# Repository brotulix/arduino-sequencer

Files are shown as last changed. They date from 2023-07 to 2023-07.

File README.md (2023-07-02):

# arduino-sequencer
A simple Arduino-based sequencer to turn masthead preamplifier and power amplifier on and off in sequence when beginning and ending transmission, as well as inhibiting transmit on a Yaesu radio (FT-991 or FT-817).

Additions will be switching coax relays to allow co-listening with an SDR during receive period.

## PTT

The same sequencer is intended for 144 and 432 MHz operation, for which I own power amplifiers with opposite PTT controls; one will activate when PTT is pulled high, one will activate when PTT is pulled low. To solve this with the least hassle, I'll control the PTT using a photo diode surrounded by four diodes, and select active high or active low using a toggle switch:

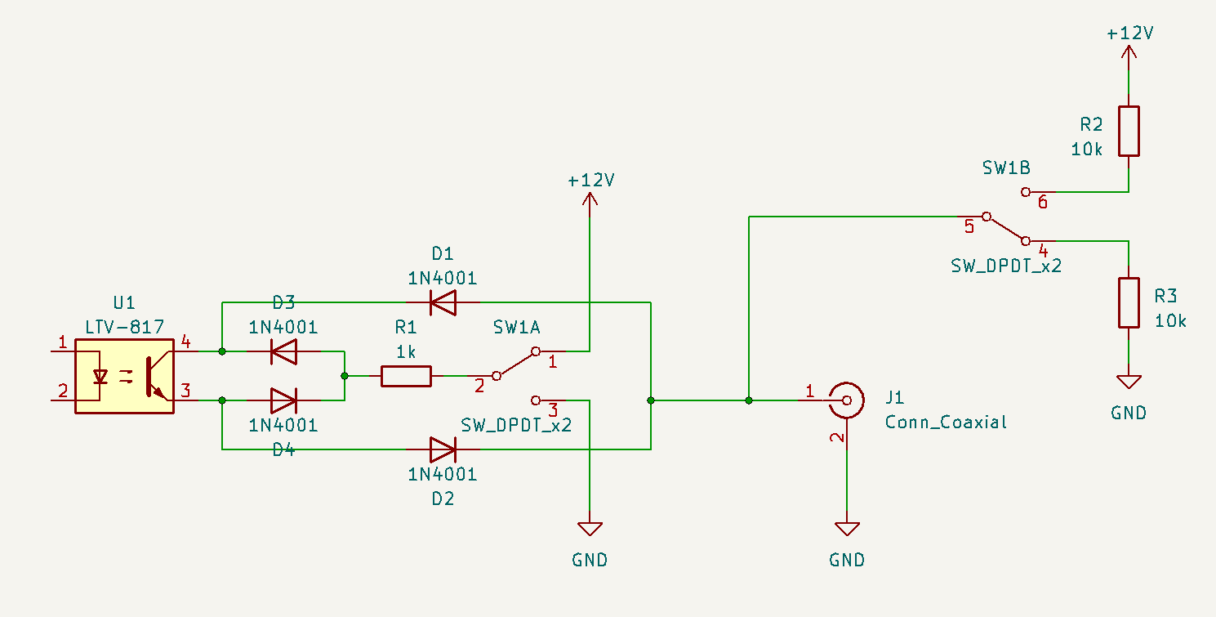
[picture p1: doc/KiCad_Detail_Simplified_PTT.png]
Simplified PA PTT circuit


Here, J1 (an RCA socket) connects to the PTT input of either KLM electronics VHF PA or Microwave Modules MML 432/100 UHF PA. SW1 is DPDT and will flip voltages for both the opto-coupler and the pull up/down.

# State machine
So, a state machine may be a useful method to keep track of where one is in the sequence of events going from RX -> TX or TX -> RX.

Maybe some form of table-based state machine to easily add stages and transitioning to the right next state?

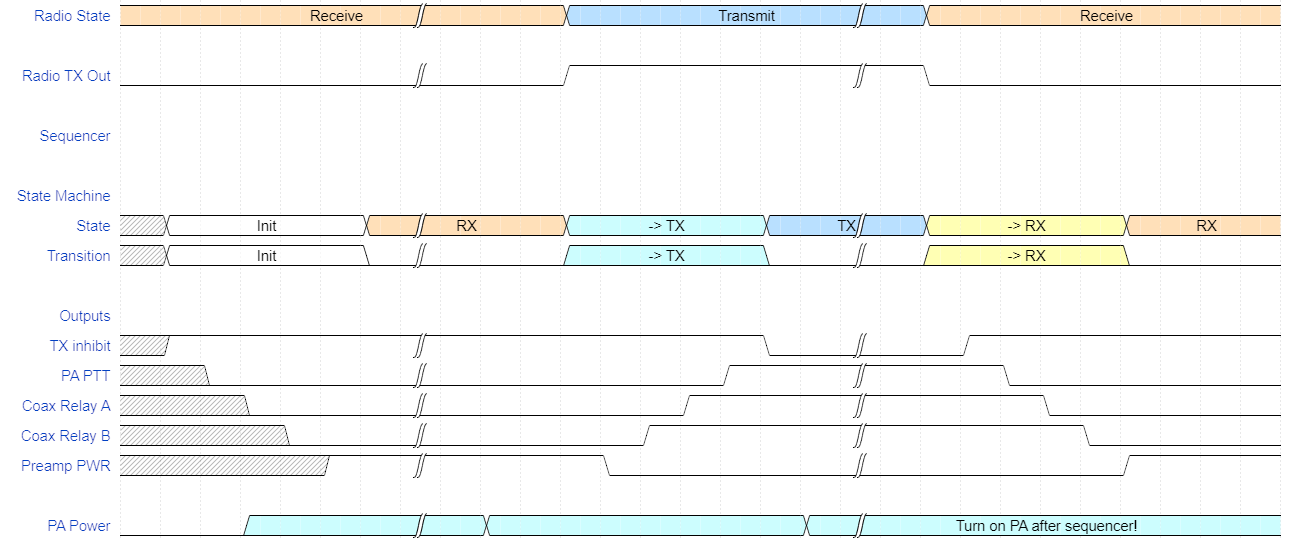
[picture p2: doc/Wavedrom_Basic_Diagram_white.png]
Basic state machine timing diagram


Whether I'll use an interrupt to trigger on flank or simply evaluate high/low state in a loop is TBD.

## Initialization / Power-up
The system starts up in an unknown state as of yet. I think it should sets some signals to a safe-ish state immediately, then progresses through some sequence of events to reach a true RX state.

Probably the most important detail is that the PA should be switched on after the sequencer.

> Should the radio be switched on after the sequencer, too, to make sure TX inhibit is on from the start?

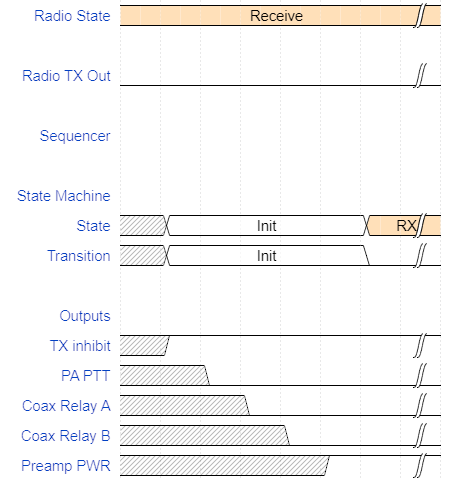
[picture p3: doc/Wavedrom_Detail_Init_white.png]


## RX -> TX
The sequence when going from RX to TX is something like this:

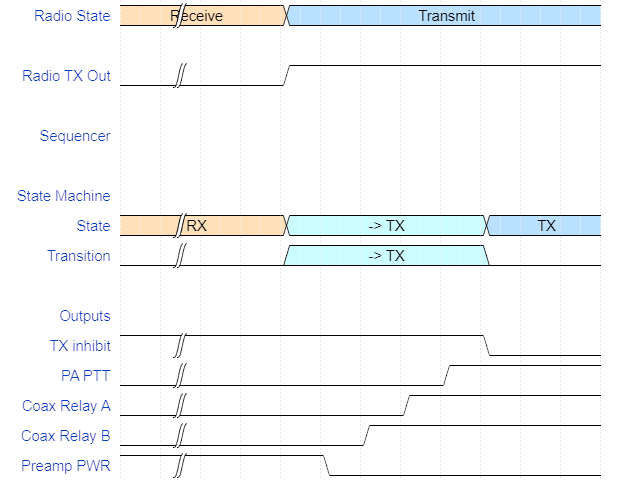
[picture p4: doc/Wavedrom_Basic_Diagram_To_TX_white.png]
Generic timing diagram for state transition from TX to RX


### RX -> TX -> RX
The special case when TX goes low before during the transition from RX to TX should go something like this:

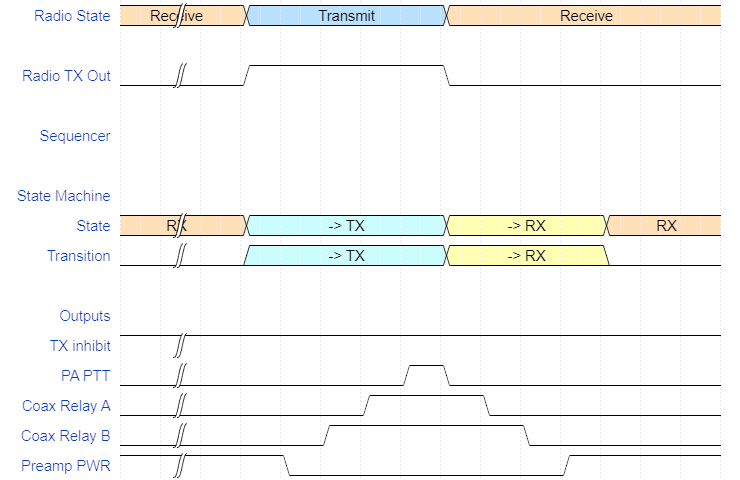
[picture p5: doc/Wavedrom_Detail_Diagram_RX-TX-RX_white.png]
Generic timing diagram for state transition from RX, partly to TX, then back to RX


See *dwell time*.

## TX -> RX
Transitioning from TX back to RX:

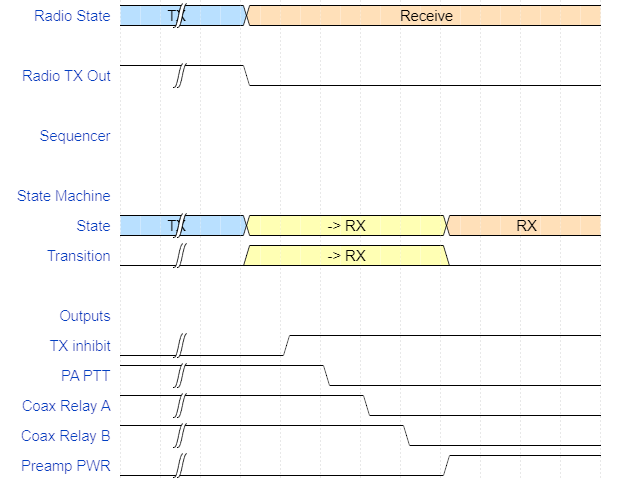
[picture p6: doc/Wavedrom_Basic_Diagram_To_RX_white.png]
Timing diagram for state transition from TX to RX


### TX -> RX -> TX
The special case where one is transmitting, but then experience a glitch in TX from radio which begins a transition to RX, but then returns to TX during the transition phase.

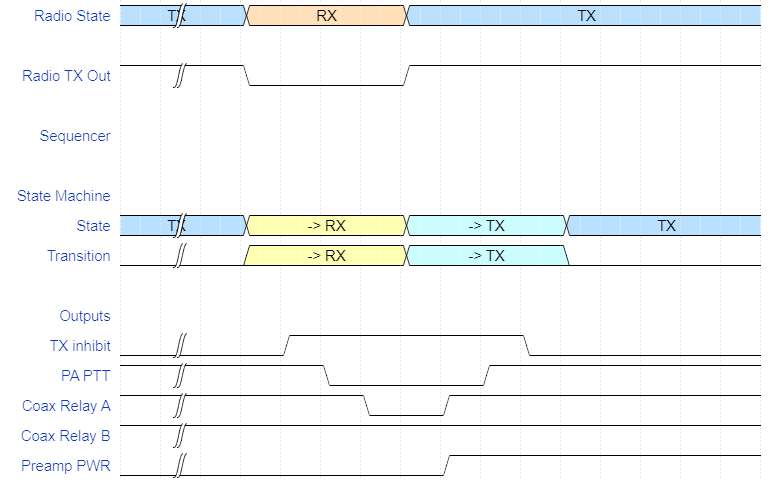
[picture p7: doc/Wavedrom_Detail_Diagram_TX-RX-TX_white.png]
Timing diagram for state transition from RX, partly to TX, then back to RX


See *dwell time*.

# Dwell time
> Add a potensiometer/encoder to set the delay for each stage? First design may use the same delay for both entering and leaving transmit state, but perhaps allow for faster delays going one direction or the other later?

Upon entering every state, set a minimum dwell time for that state to allow for energy to stabilize in the system (eg. DC bias for preamp; depending on coax length, you may want a certain minimum delay to allow the rising edge to reach full round-trip).

This may remove the need for a "inter-state" delay period, and depending on what the Radio TX signal is when entering (or exiting) the state determines which direction one goes. So, in principle, by toggling TX line fast enough, it may be possible to stay in the twilight zone between RX and TX indefinitely?

# Blinkenlights
I'm thinking a front panel that shows what state the in- and outputs are in. Should at least help during development when the timing probably is way longer than necessary.

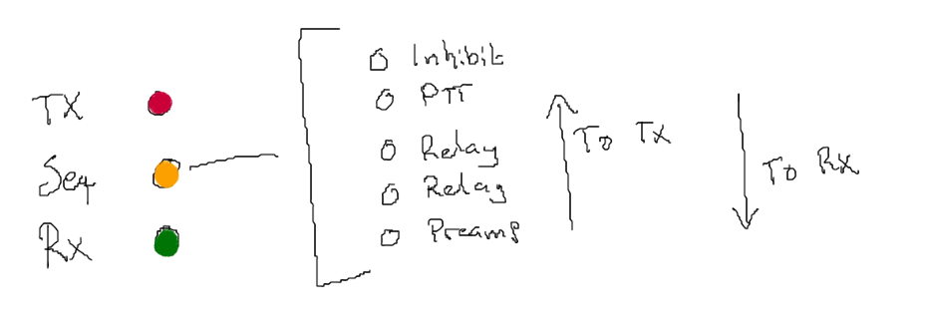
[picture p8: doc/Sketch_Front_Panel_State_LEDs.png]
Rough sketch of front panel LEDs


The idea here is that when idle, only the green RX LED should light up. Then, when the radio activates the TX line, the red TX LED lights up, rendering the LED yellow-ish. While both of these LEDs are lit, the individual output LEDs on the side should light up from the bottom up, until all are lit, when the green RX LED goes out and only the red TX LED is lit.

> Perhaps also have the individual stages as red/green LEDs to more clearly illustrate the logic colour-code?

> Perhaps also have a fancy display that shows the current delay count-down for that extra *ooh* and *aah*, at least during development?

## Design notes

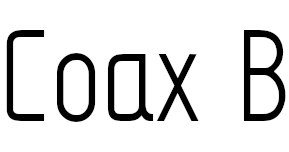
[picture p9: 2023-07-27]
solidedge/Labels/Coax B.png

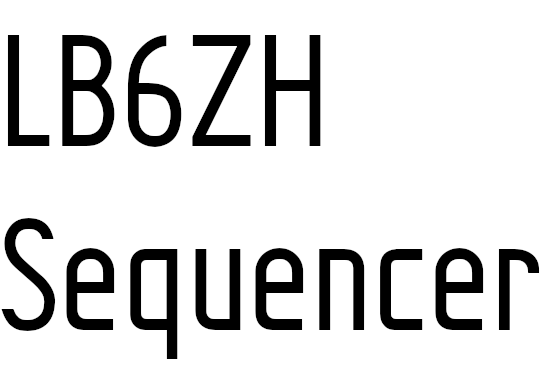
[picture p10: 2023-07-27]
solidedge/Labels/LB6ZH Sequencer.png

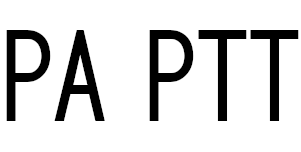
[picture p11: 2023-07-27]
solidedge/Labels/PA PTT.png

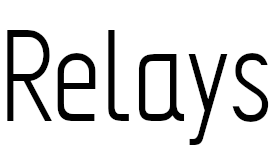
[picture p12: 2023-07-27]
solidedge/Labels/Relays.png

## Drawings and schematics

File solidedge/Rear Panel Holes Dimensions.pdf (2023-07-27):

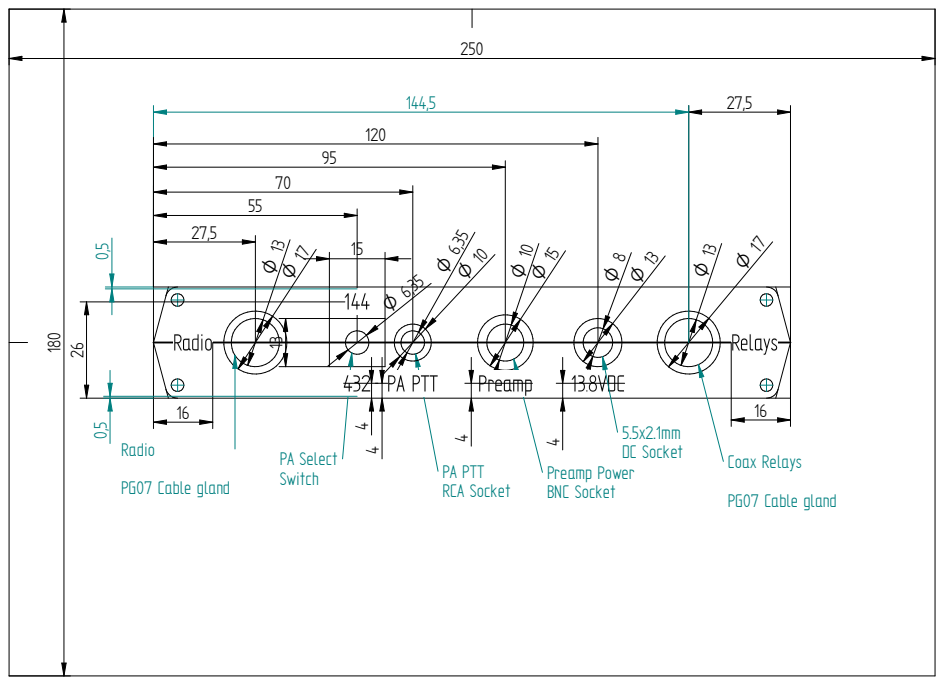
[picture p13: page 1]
Radio; PG07 Cable gland; Coax Relays; Preamp Power BNC Socket; PA PTT RCA Socket; PA Select Switch; 5.5x2.1mm DC Socket

144,5 27,5
120

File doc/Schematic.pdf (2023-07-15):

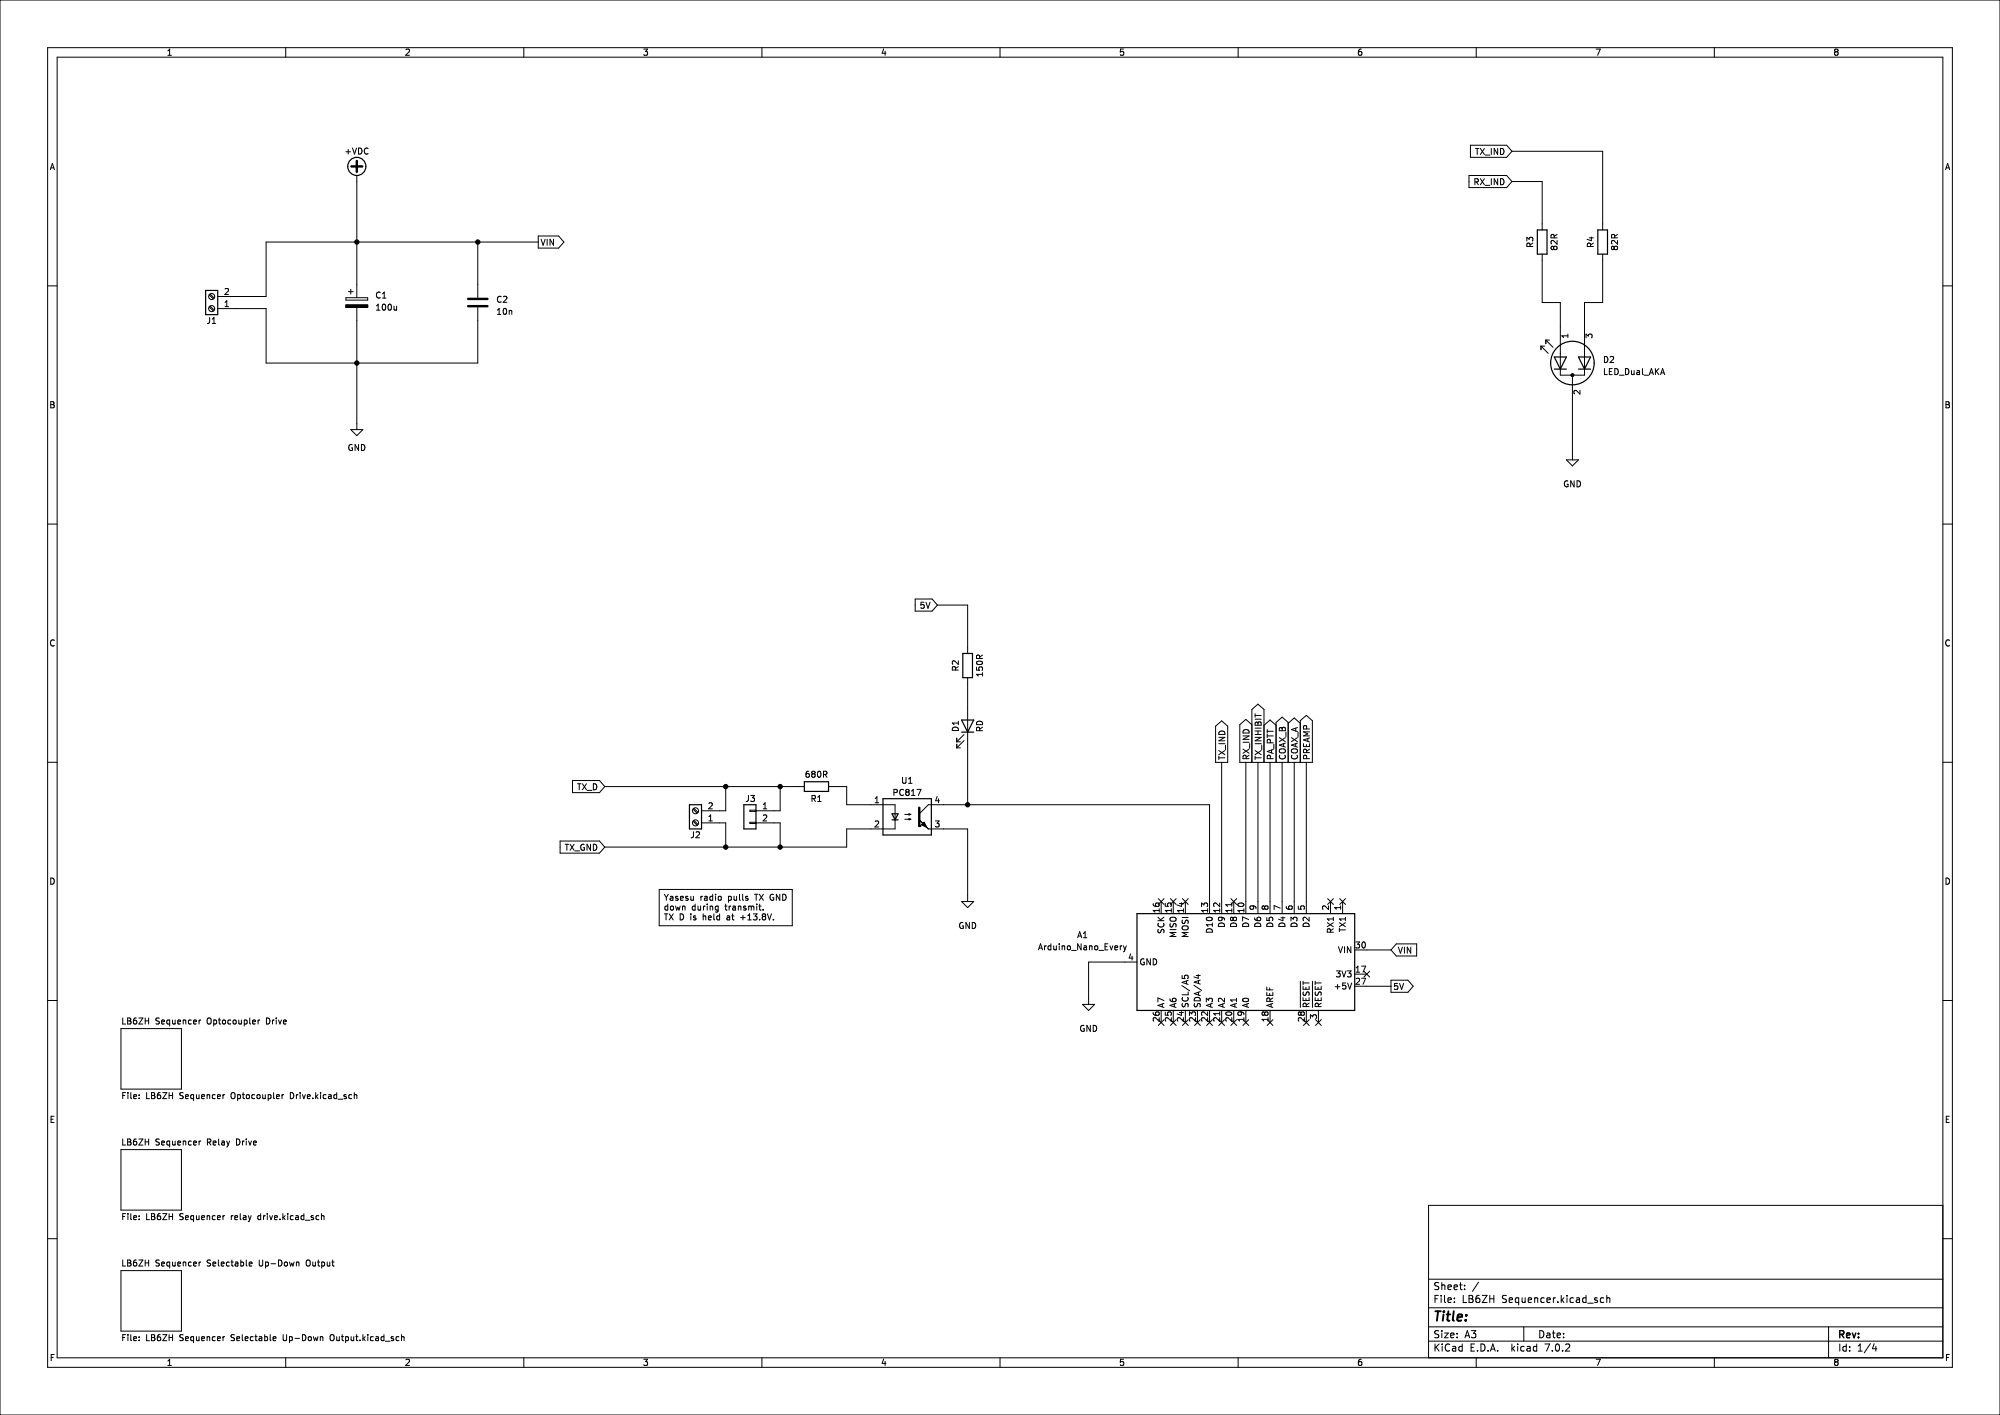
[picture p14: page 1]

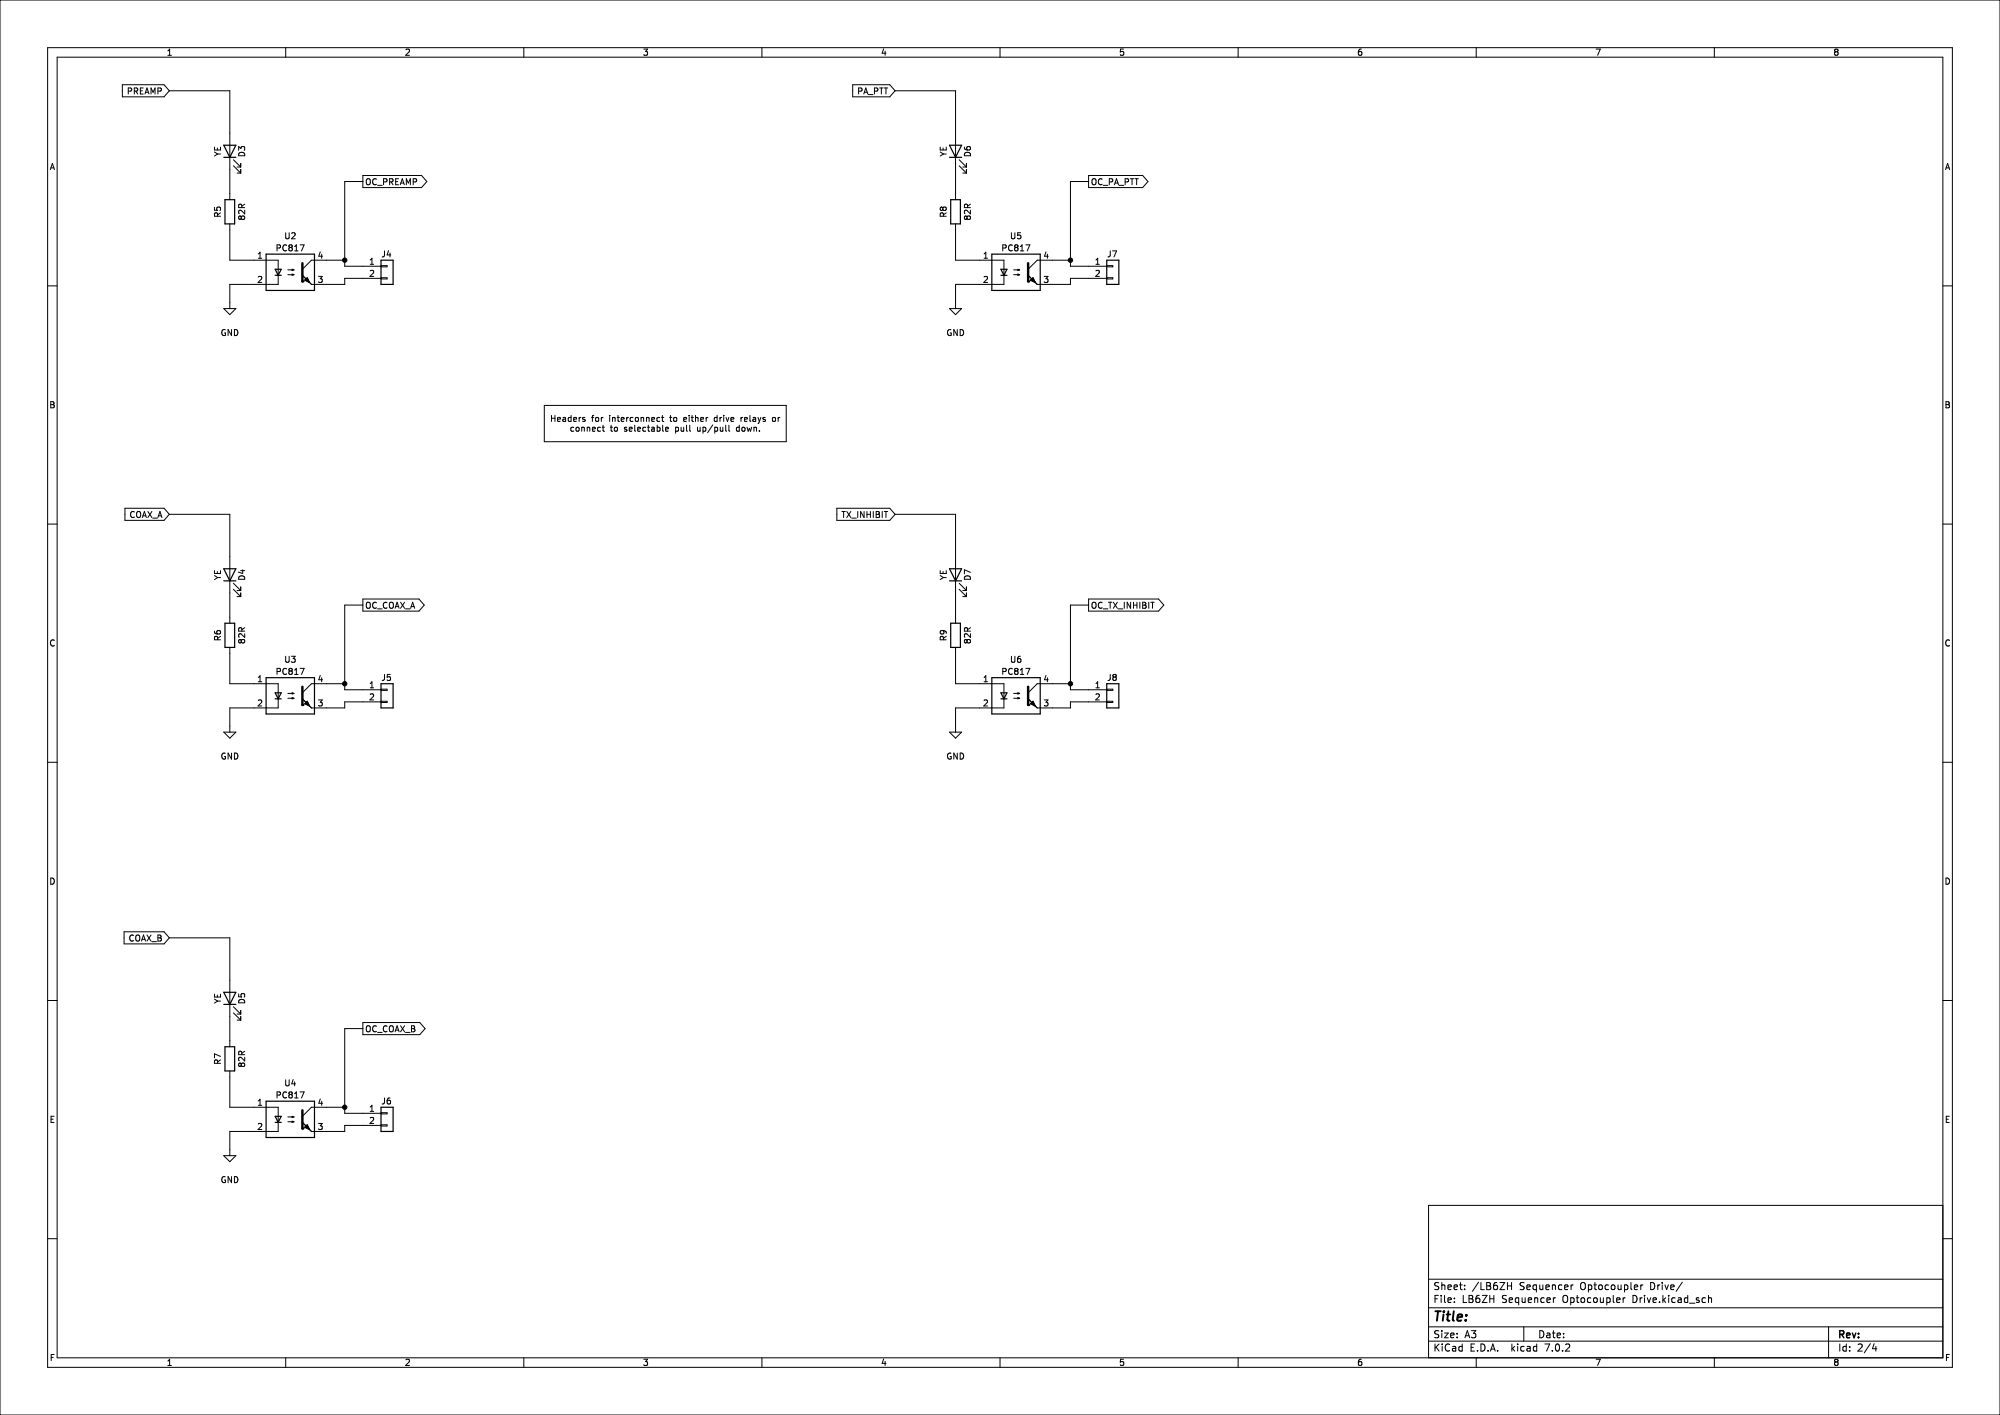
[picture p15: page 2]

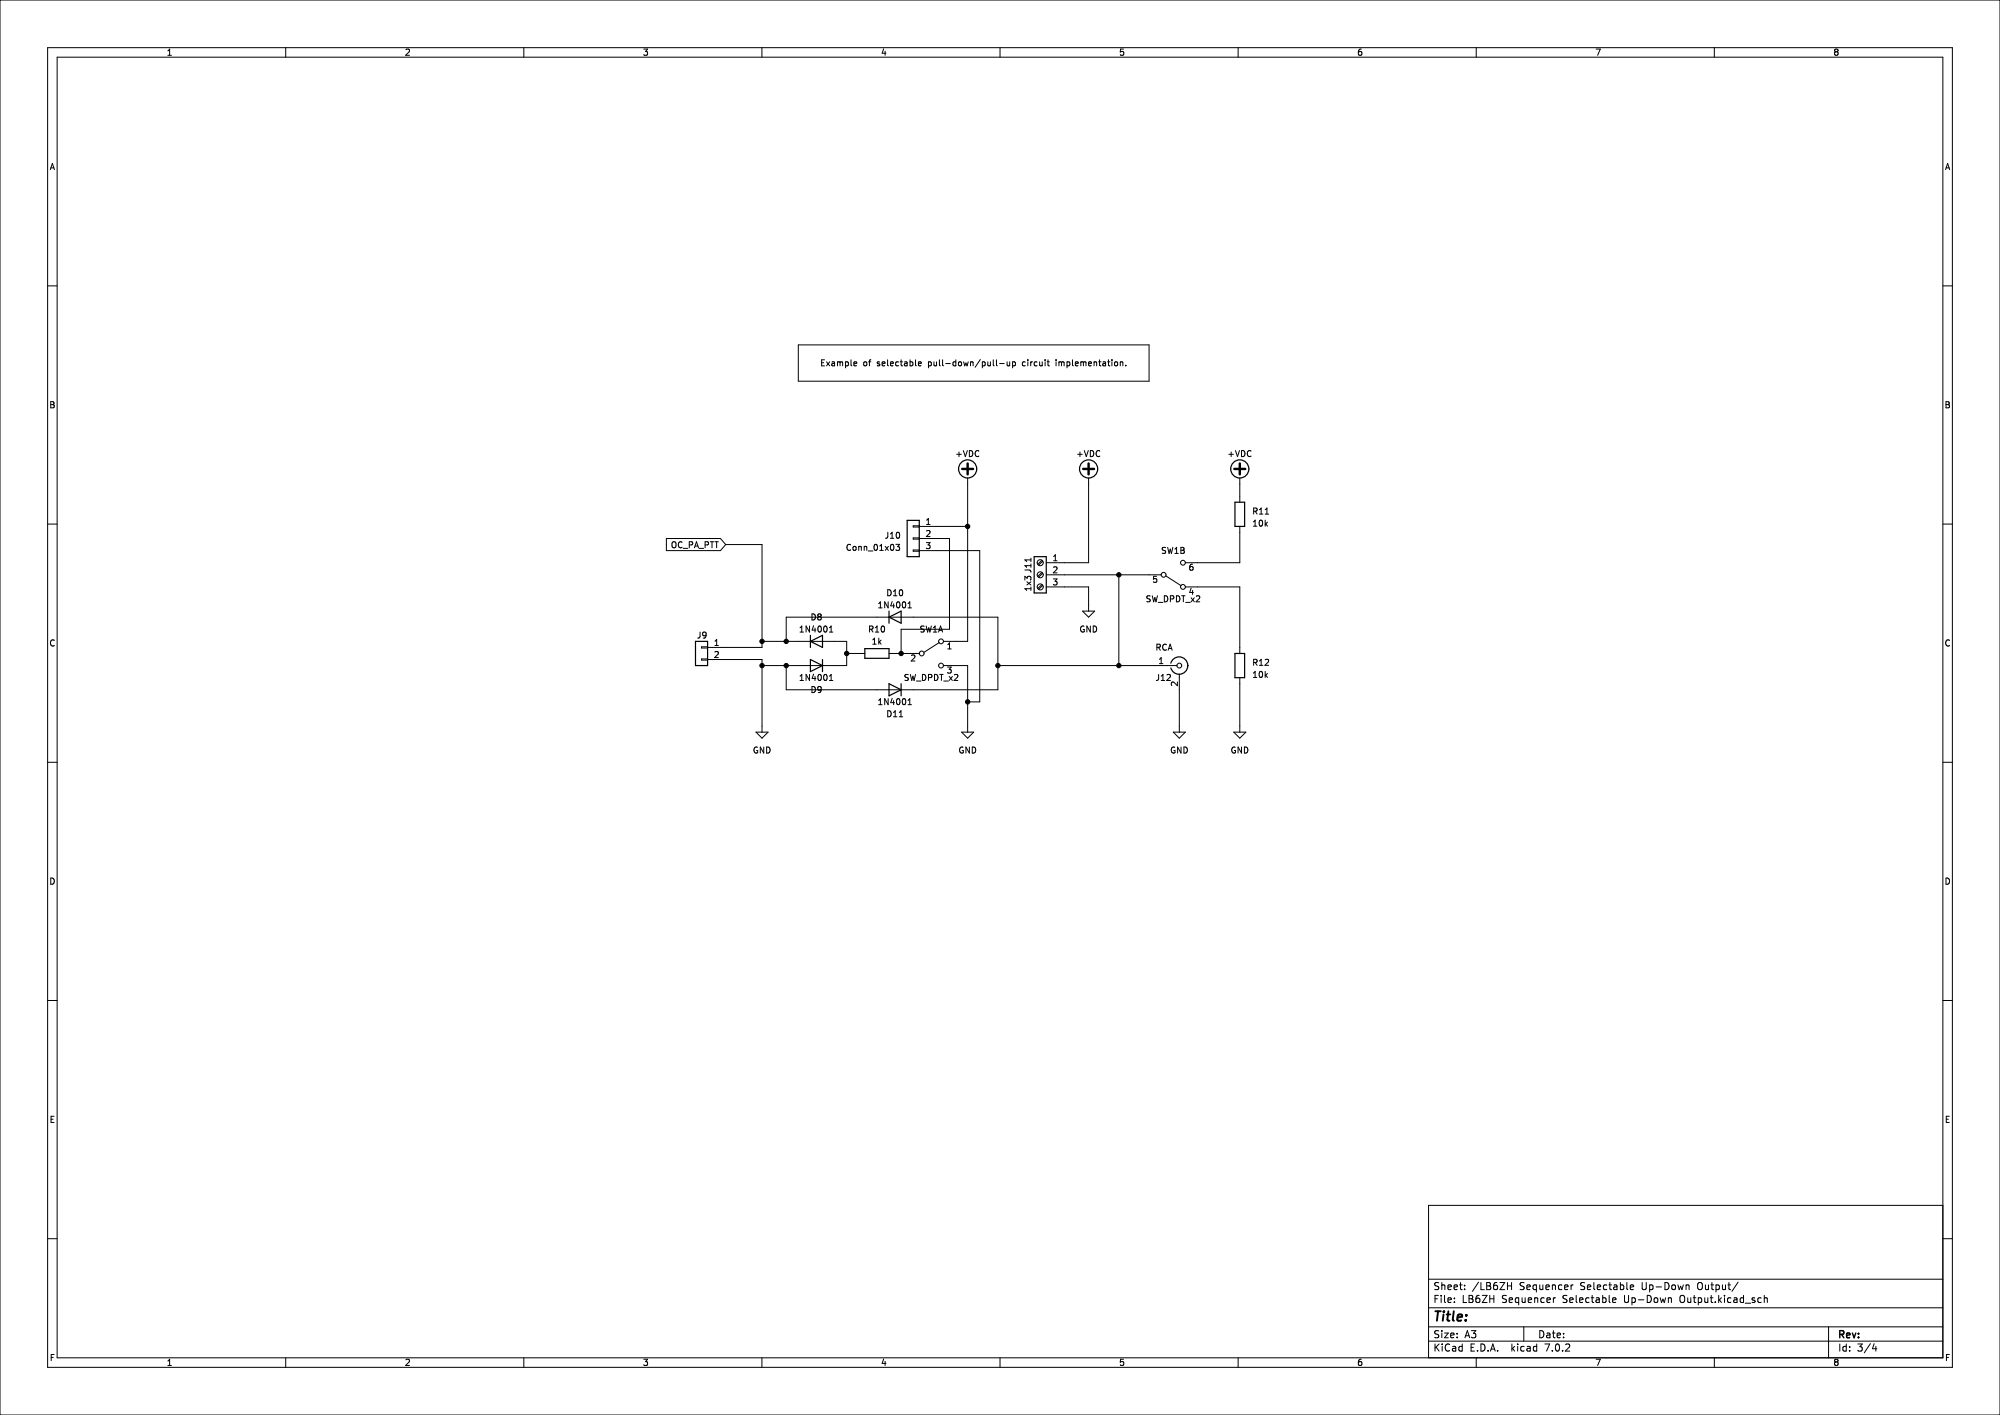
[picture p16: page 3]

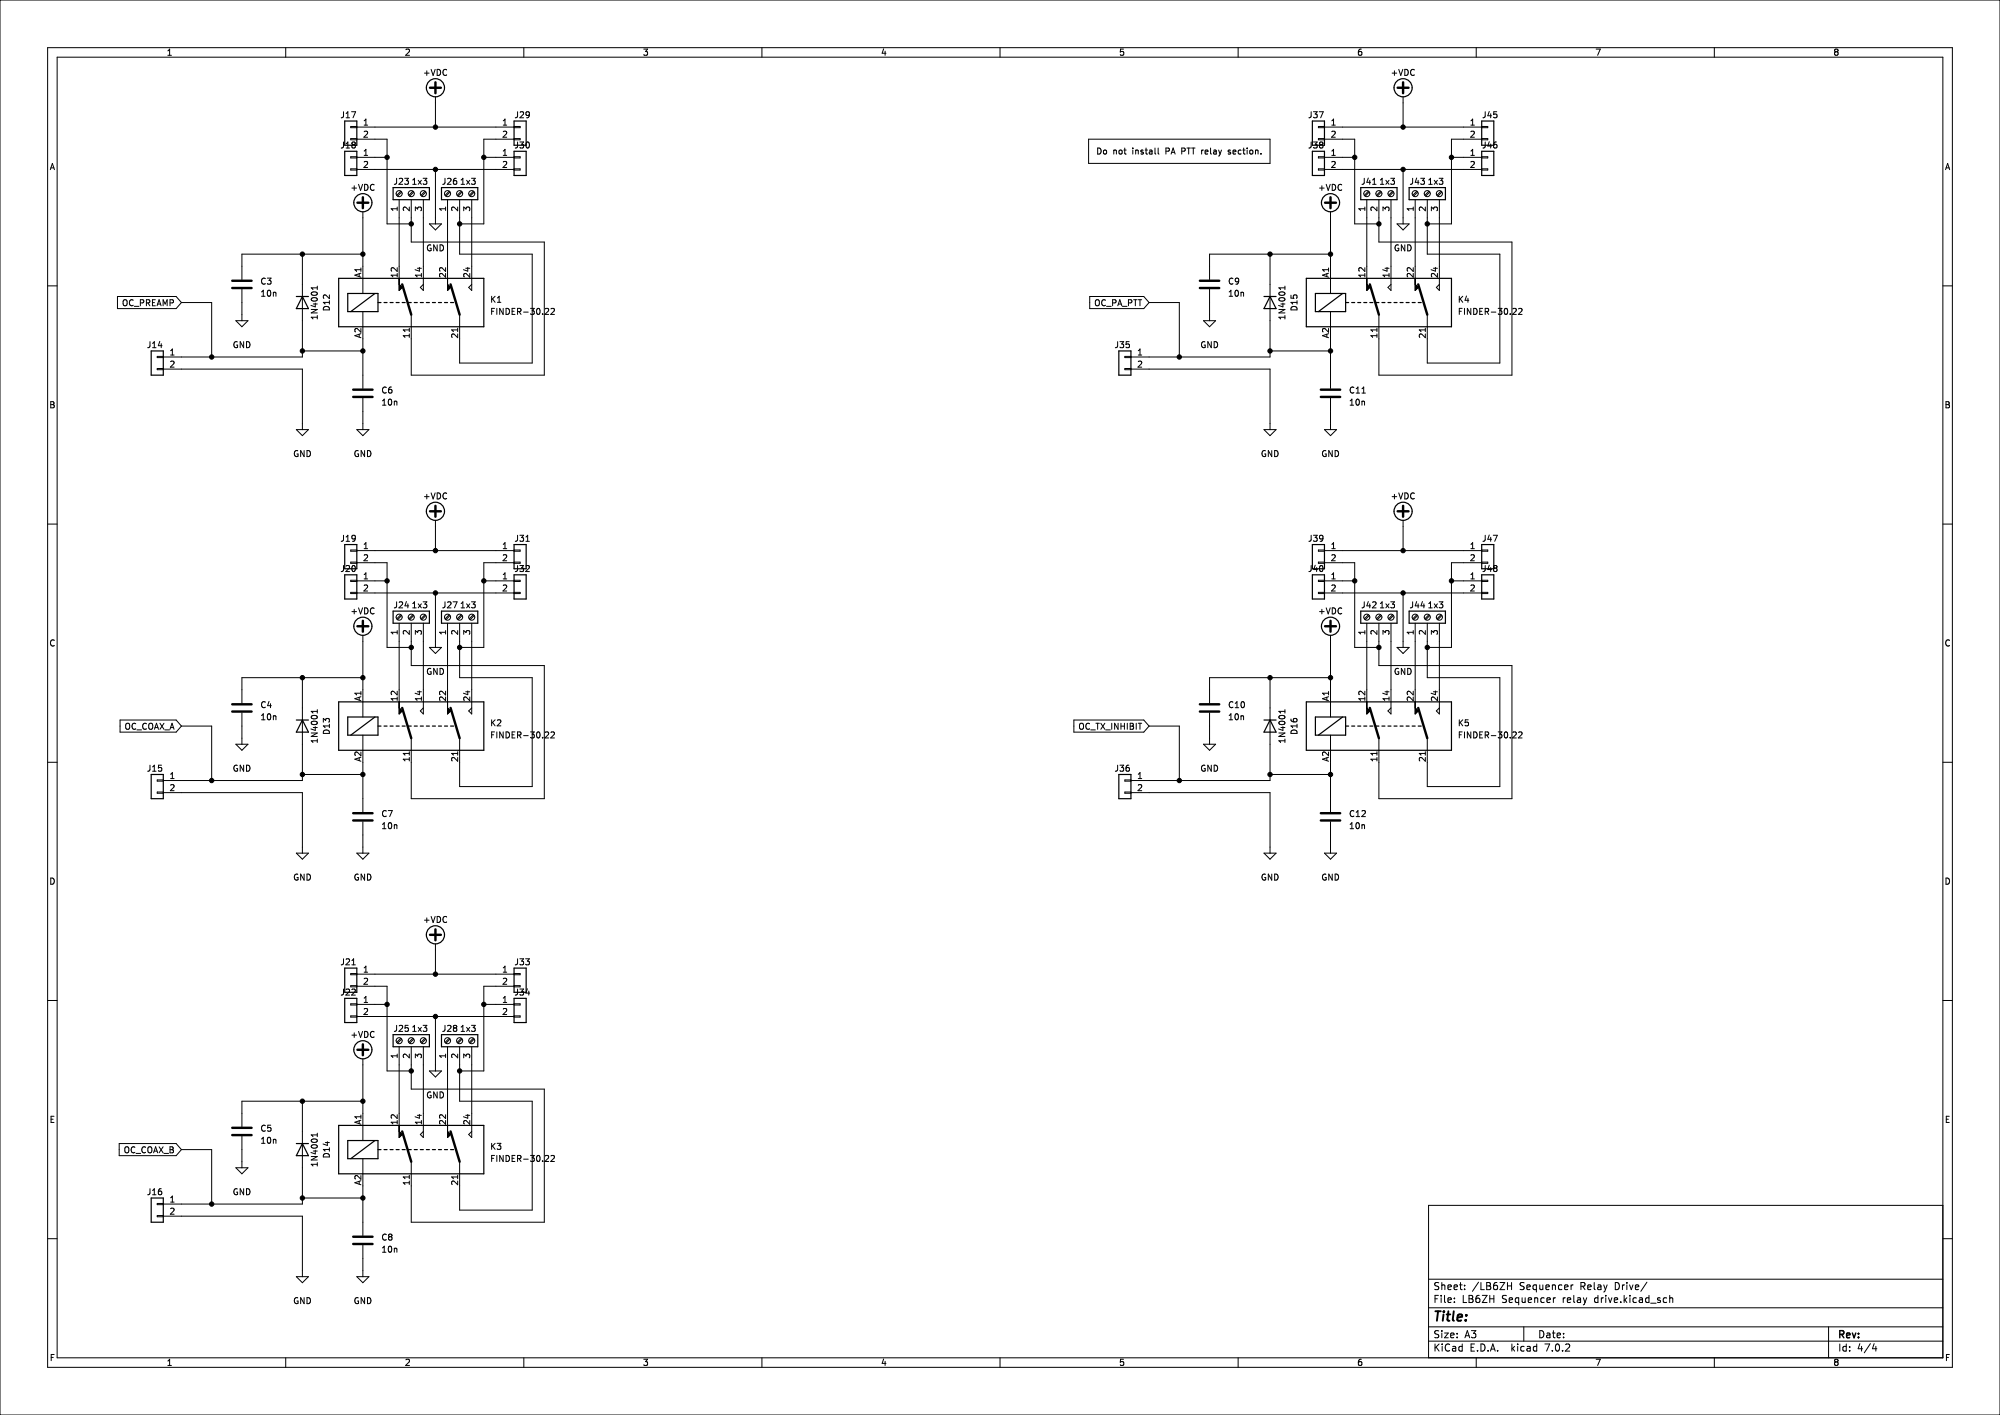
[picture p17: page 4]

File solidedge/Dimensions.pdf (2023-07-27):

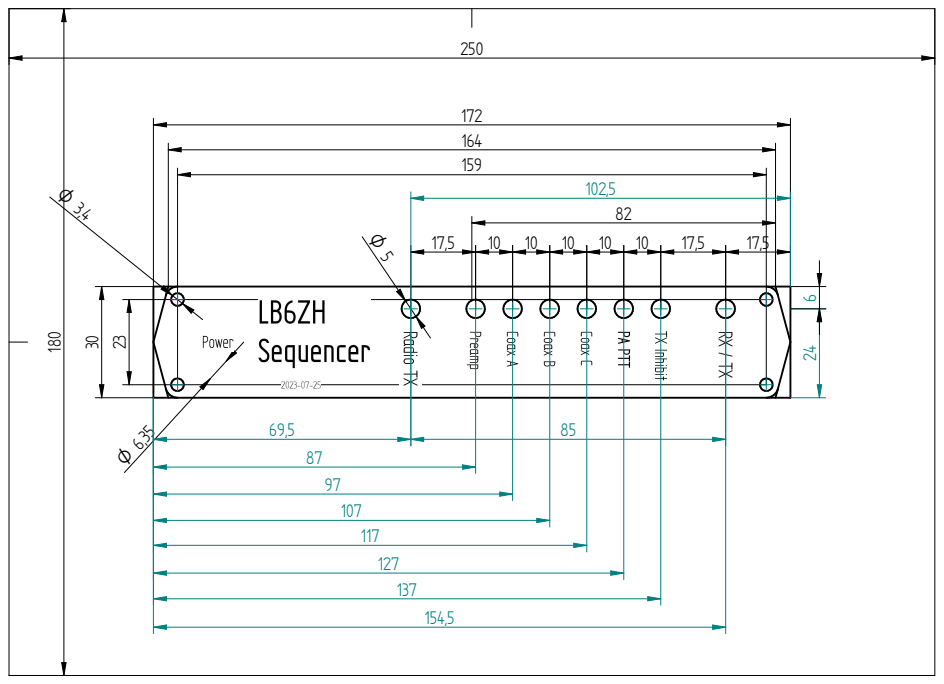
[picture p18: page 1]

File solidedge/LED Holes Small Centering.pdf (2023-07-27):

250

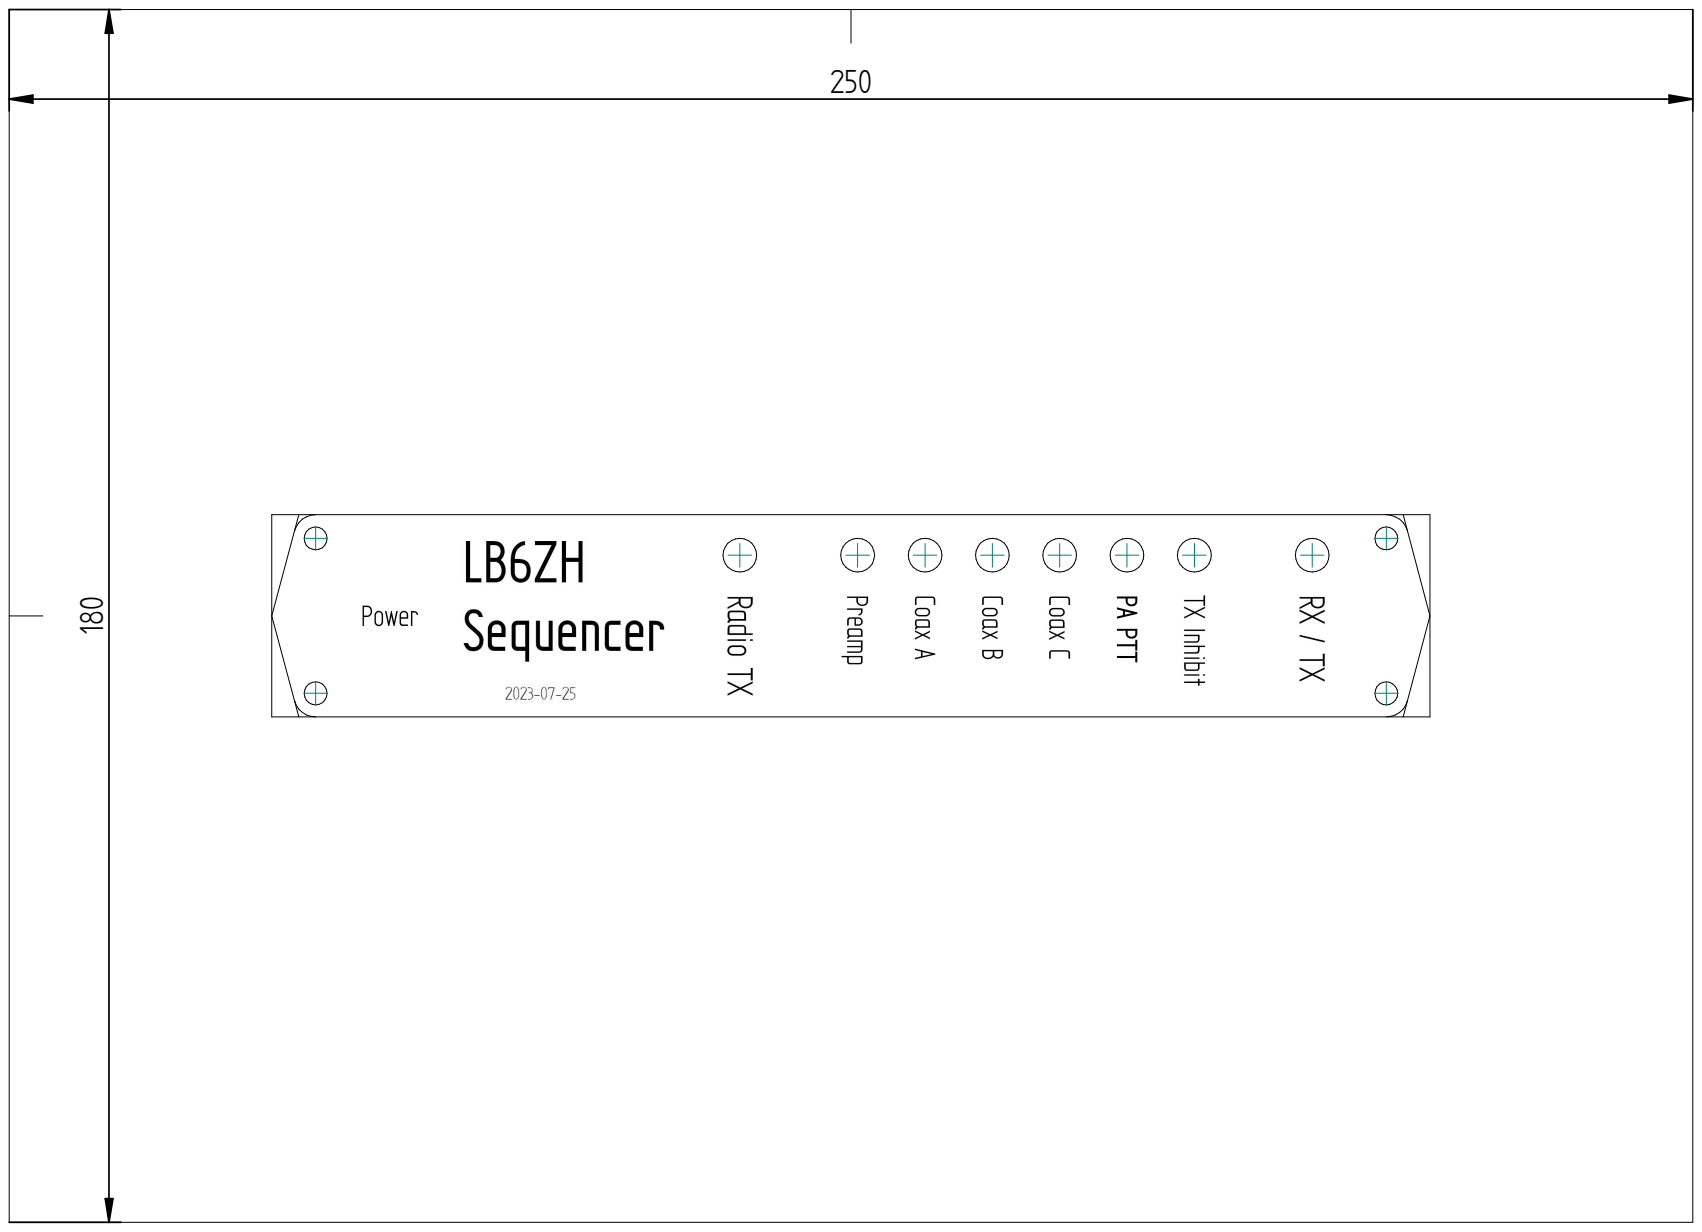
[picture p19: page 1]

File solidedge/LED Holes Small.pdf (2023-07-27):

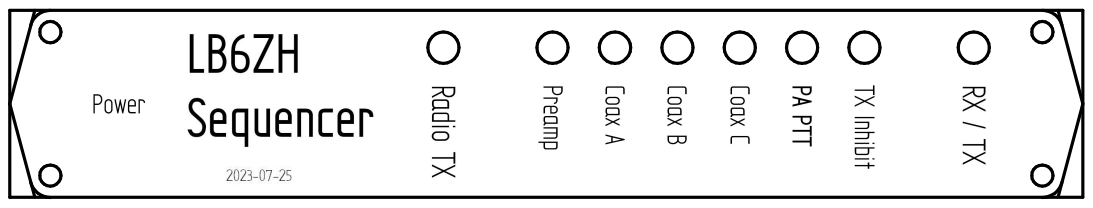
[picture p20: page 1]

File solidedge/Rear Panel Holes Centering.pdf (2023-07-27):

250

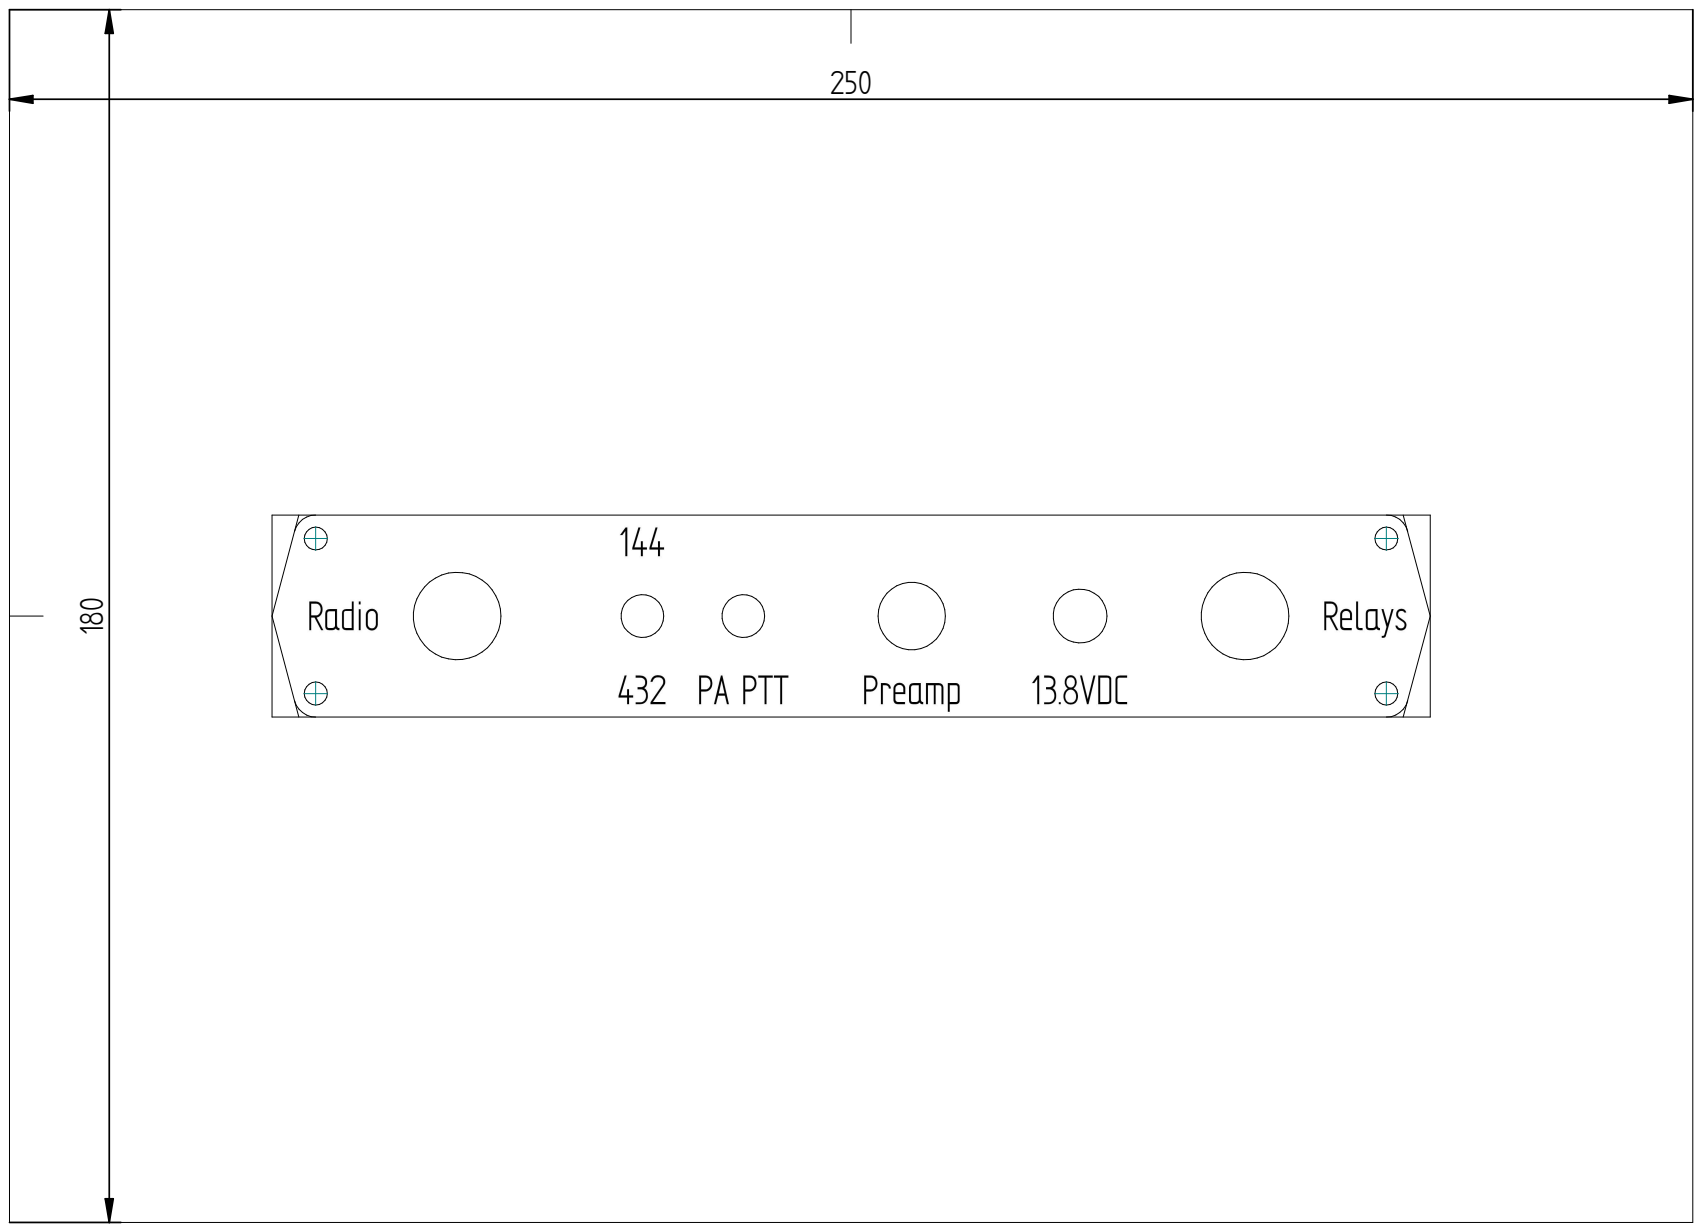
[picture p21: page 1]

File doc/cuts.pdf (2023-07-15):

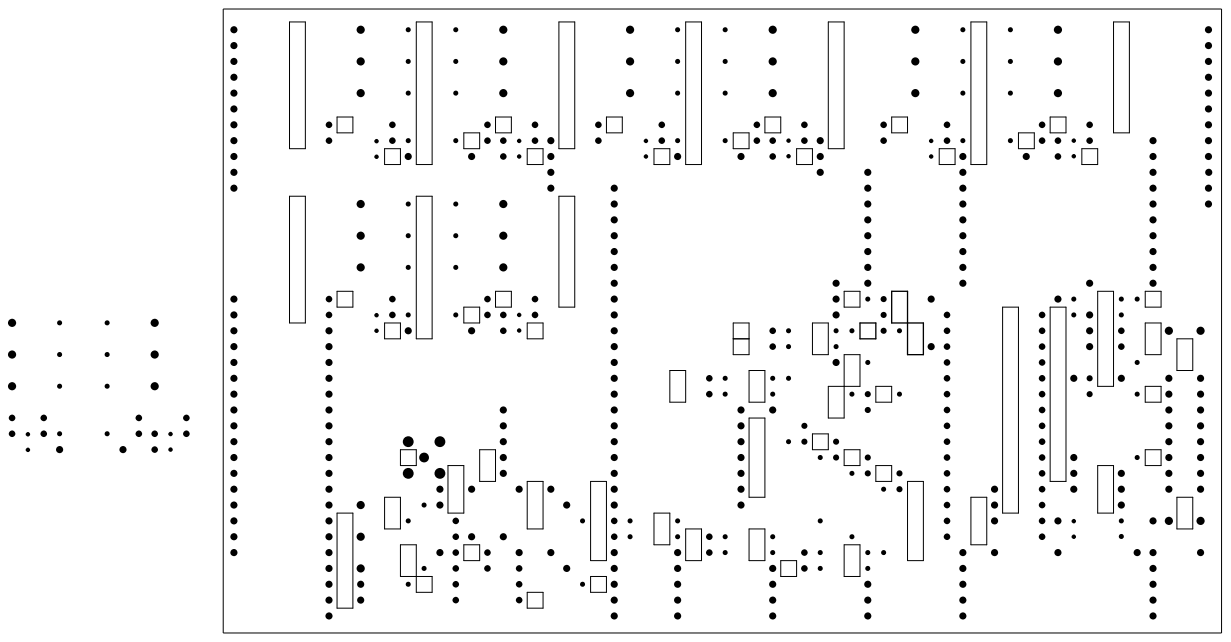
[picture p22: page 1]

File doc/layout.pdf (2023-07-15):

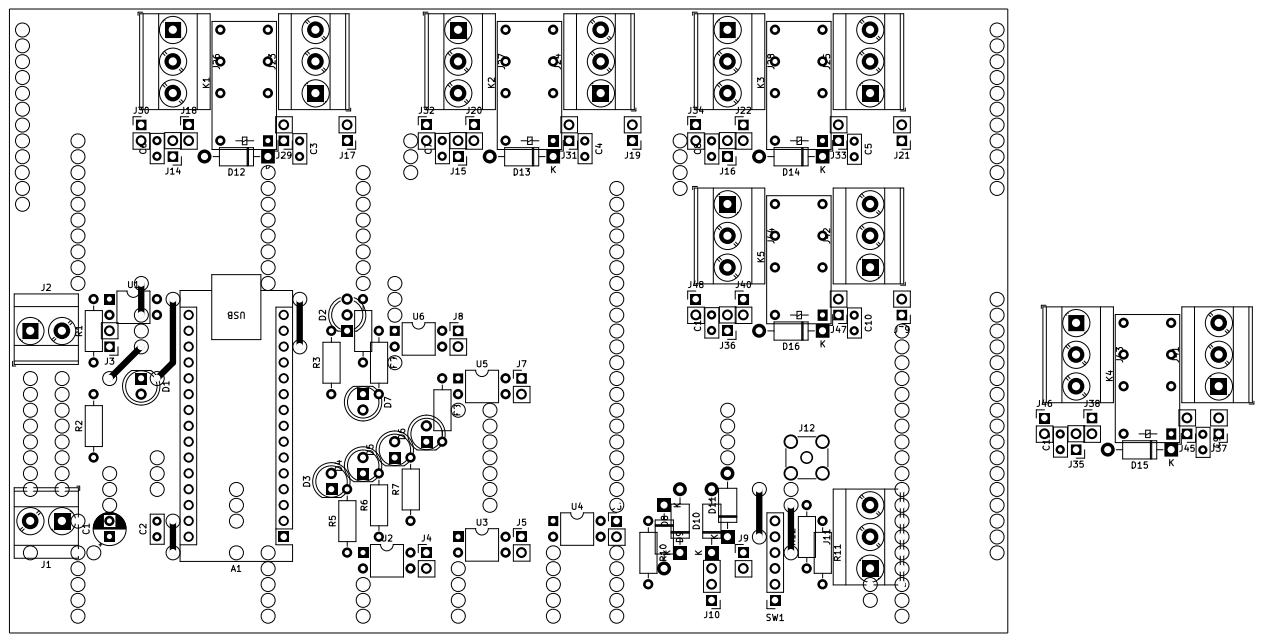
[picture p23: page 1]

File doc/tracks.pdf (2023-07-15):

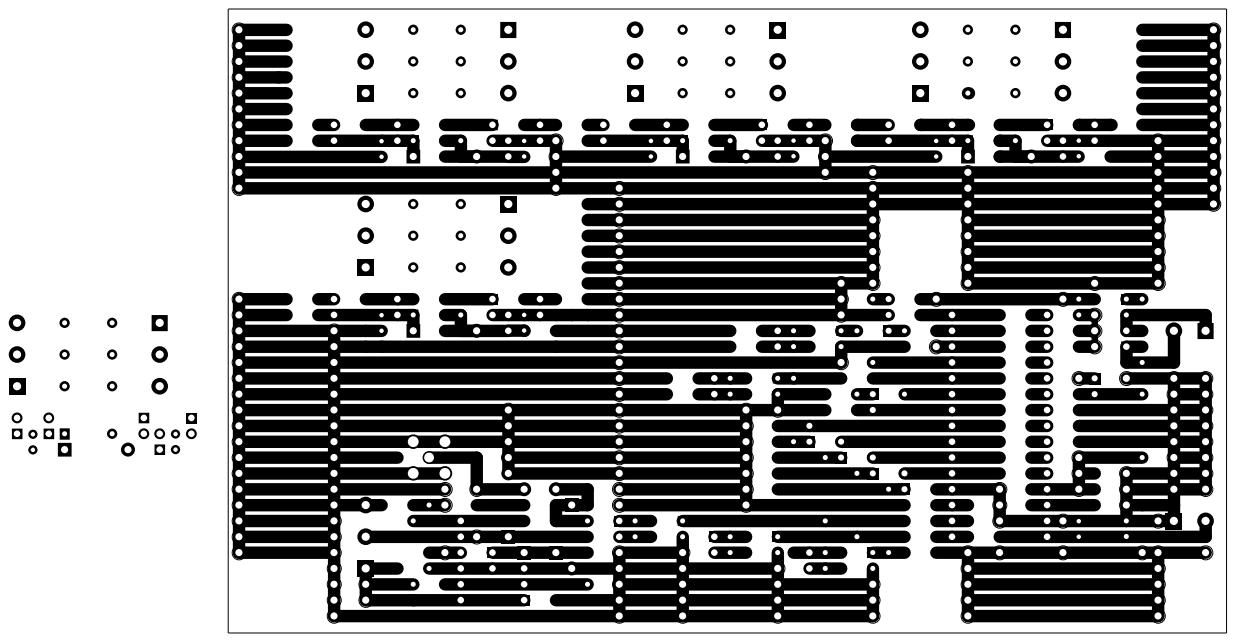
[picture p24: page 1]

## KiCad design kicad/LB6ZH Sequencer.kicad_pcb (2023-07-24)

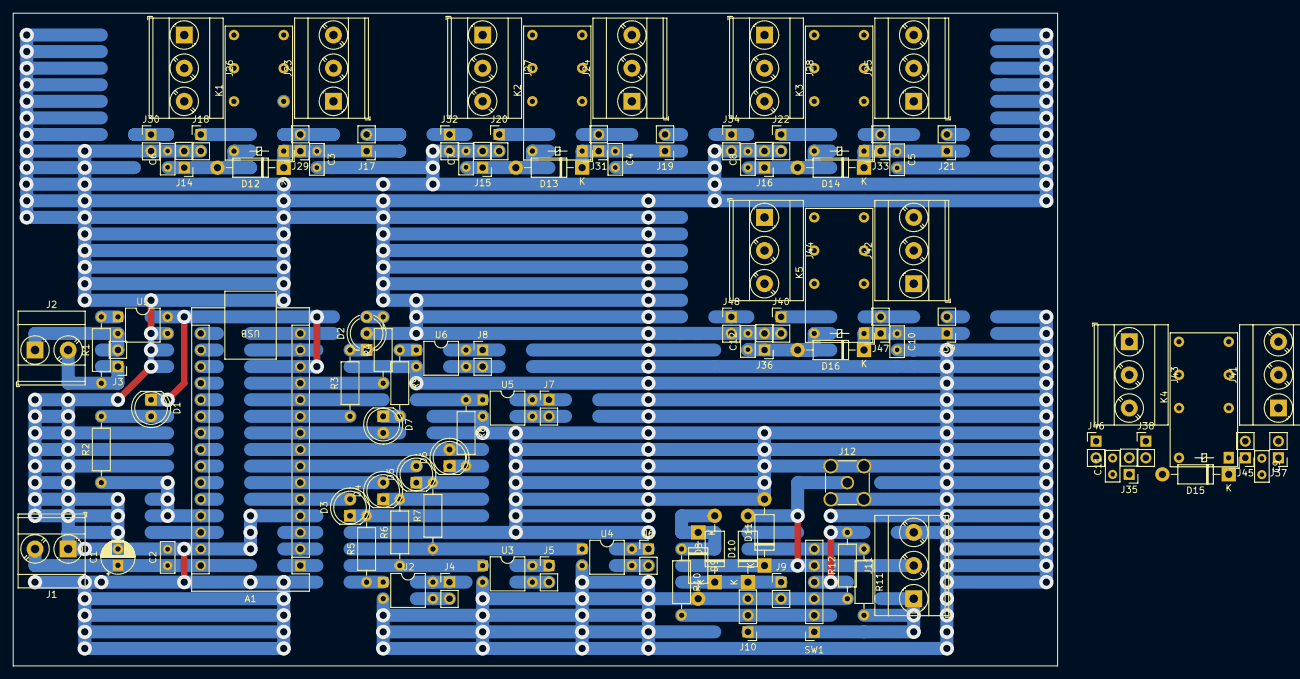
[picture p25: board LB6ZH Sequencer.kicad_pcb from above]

Board: 2 copper layers, 160.0 x 100.0 mm, 100 parts (0 on the bottom side), 72 nets.

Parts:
A1: Arduino_Nano_Every; Arduino_Nano
C1: 100u; CP_Radial_D5.0mm_P2.50mm
C2, C3, C4, C5, C6, C7, C8, C9, C10, C11, C12: 10n; C_Rect_L4.6mm_W2.0mm_P2.50mm_MKS02_FKP02
D1: RD; LED_D5.0mm_Clear
D2: LED_Dual_AKA; LED_D5.0mm-3
D3, D4, D5, D6, D7: YE; LED_D5.0mm_Clear
D8, D9, D10, D11, D12, D13, D14, D15, D16: 1N4001; D_DO-41_SOD81_P10.16mm_Horizontal
J1: 1x2; TerminalBlock_Phoenix_MKDS-3-2-5.08_1x02_P5.08mm_Horizontal
J2: Screw_Terminal_01x02; TerminalBlock_Phoenix_MKDS-3-2-5.08_1x02_P5.08mm_Horizontal
J3, J4, J5, J6, J7, J8, J9, J14, J15, J16, J17, J18, J19, J20, J21, J22, J29, J30, J31, J32, J33, J34, J35, J36, J37, J38, J39, J40, J45, J46, J47, J48: Conn_01x02; PinHeader_1x02_P2.54mm_Vertical
J10: Conn_01x03; PinHeader_1x03_P2.54mm_Vertical
J11, J23, J24, J25, J26, J27, J28, J41, J42, J43, J44: 1x3; TerminalBlock_Phoenix_MKDS-3-3-5.08_1x03_P5.08mm_Horizontal
J12: RCA; SMA_Amphenol_901-144_Vertical
K1, K2, K3, K4, K5: FINDER-30.22; Relay_DPDT_Finder_30.22
R1: 680R; R_Axial_DIN0207_L6.3mm_D2.5mm_P10.16mm_Horizontal
R2: 150R; R_Axial_DIN0207_L6.3mm_D2.5mm_P10.16mm_Horizontal
R3, R4, R5, R6, R7, R8, R9: 82R; R_Axial_DIN0207_L6.3mm_D2.5mm_P10.16mm_Horizontal
R10: 1k; R_Axial_DIN0207_L6.3mm_D2.5mm_P10.16mm_Horizontal
R11, R12: 10k; R_Axial_DIN0207_L6.3mm_D2.5mm_P10.16mm_Horizontal
SW1: SW_DPDT_x2; PinSocket_1x06_P2.54mm_Vertical
U1, U2, U3, U4, U5, U6: PC817; DIP-4_W7.62mm

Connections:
5V: A1.27 (+5V), R2.1
COAX_A: A1.6 (D3), D4.2 (A)
COAX_B: A1.7 (D4), D5.2 (A)
GND: A1.4 (GND), A1.29 (GND), C1.2, C2.2, C3.2, C4.2, C5.2, C6.2, C7.2, C8.2, C9.2, C10.2, C11.2, C12.2, D2.2 (K), D9.2 (A), D11.2 (A), J1.1, J9.2, J10.3, J11.3, J12.2 (Ext), J14.2, J15.2, J16.2, J18.2, J20.2, J22.2, J30.2, J32.2, J34.2, J35.2, J36.2, J38.2, J40.2, J46.2, J48.2, R12.1, SW1.3 (C), U1.3, U2.2, U3.2, U4.2, U5.2, U6.2
unnamed: A1.13 (D10), D1.1 (K), U1.4
unnamed: D1.2 (A), R2.2
unnamed: D2.1 (A1), R3.2
unnamed: D2.3 (A2), R4.2
unnamed: D3.1 (K), R5.2
unnamed: D4.1 (K), R6.2
unnamed: D5.1 (K), R7.2
unnamed: D6.1 (K), R8.2
unnamed: D7.1 (K), R9.2
unnamed: D8.2 (A), D9.1 (K), R10.1
unnamed: D10.2 (A), D11.1 (K), J11.2, J12.1 (In), SW1.5 (B)
unnamed: J4.2, U2.3
unnamed: J5.2, U3.3
unnamed: J6.2, U4.3
unnamed: J7.2, U5.3
unnamed: J8.2, U6.3
unnamed: J10.2, R10.2, SW1.2 (B)
unnamed: J17.2, J18.1, J23.2, K1.11
unnamed: J19.2, J20.1, J24.2, K2.11
unnamed: J21.2, J22.1, J25.2, K3.11
unnamed: J23.1, K1.12
unnamed: J23.3, K1.14
unnamed: J24.1, K2.12
unnamed: J24.3, K2.14
unnamed: J25.1, K3.12
unnamed: J25.3, K3.14
unnamed: J26.1, K1.22
unnamed: J26.2, J29.2, J30.1, K1.21
unnamed: J26.3, K1.24
unnamed: J27.1, K2.22
unnamed: J27.2, J31.2, J32.1, K2.21
unnamed: J27.3, K2.24
unnamed: J28.1, K3.22
unnamed: J28.2, J33.2, J34.1, K3.21
unnamed: J28.3, K3.24
unnamed: J37.2, J38.1, J41.2, K4.11
unnamed: J39.2, J40.1, J42.2, K5.11
unnamed: J41.1, K4.12
unnamed: J41.3, K4.14
unnamed: J42.1, K5.12
unnamed: J42.3, K5.14
unnamed: J43.1, K4.22
unnamed: J43.2, J45.2, J46.1, K4.21
unnamed: J43.3, K4.24
unnamed: J44.1, K5.22
unnamed: J44.2, J47.2, J48.1, K5.21
unnamed: J44.3, K5.24
unnamed: R1.2, U1.1
unnamed: R5.1, U2.1
unnamed: R6.1, U3.1
unnamed: R7.1, U4.1
unnamed: R8.1, U5.1
unnamed: R9.1, U6.1
unnamed: R12.2, SW1.4 (A)
unnamed: R11.1, SW1.6 (C)
OC_COAX_A: C7.1, D13.2 (A), J5.1, J15.1, K2.A2, U3.4
OC_COAX_B: C8.1, D14.2 (A), J6.1, J16.1, K3.A2, U4.4
OC_PA_PTT: C11.1, D8.1 (K), D10.1 (K), D15.2 (A), J7.1, J9.1, J35.1, K4.A2, U5.4
OC_PREAMP: C6.1, D12.2 (A), J4.1, J14.1, K1.A2, U2.4
OC_TX_INHIBIT: C12.1, D16.2 (A), J8.1, J36.1, K5.A2, U6.4
PA_PTT: A1.8 (D5), D6.2 (A)
PREAMP: A1.5 (D2), D3.2 (A)
RX_IND: A1.10 (D7), R3.1
TX_D: J2.2, J3.1, R1.1
TX_GND: J2.1, J3.2, U1.2
TX_IND: A1.12 (D9), R4.1
TX_INHIBIT: A1.9 (D6), D7.2 (A)
VIN: A1.30 (VIN), C1.1, C2.1, C3.1, C4.1, C5.1, C9.1, C10.1, D12.1 (K), D13.1 (K), D14.1 (K), D15.1 (K), D16.1 (K), J1.2, J10.1, J11.1, J17.1, J19.1, J21.1, J29.1, J31.1, J33.1, J37.1, J39.1, J45.1, J47.1, K1.A1, K2.A1, K3.A1, K4.A1, K5.A1, R11.2, SW1.1 (A)

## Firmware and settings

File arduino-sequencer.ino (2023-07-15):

#define TEST 1

// @ Todo: maybe use a mega instead for more digital I/O during development?
const int pin_preamp = 2;
const int pin_coax_relay_a = 3;
const int pin_coax_relay_b = 4;
const int pin_pa_ptt = 5;
const int pin_tx_inhibit = 6;
const int pin_rx = 7;
const int pin_tx = 9;
const int pin_txenable = 10;

const unsigned long loop_interval_ms = 50;

typedef enum
{
    STATE_UNINITIALIZED,
    STATE_RX,
    STATE_TRANSITION,
    STATE_TX,
    STATE_NUM_STATES
} states_t;

states_t state = STATE_UNINITIALIZED;

struct s_transitions
{
    states_t up;
    states_t down;
};

typedef enum
{
    LEVEL_UNINITIALIZED,
    LEVEL_RX,
    LEVEL_PREAMP,
    LEVEL_COAX_RELAY_A,
    LEVEL_COAX_RELAY_B,
    LEVEL_PA_PTT,
    LEVEL_TX_INHIBIT,
    LEVEL_TX,
    LEVEL_NUM_LEVELS
} levels_t;

levels_t level = LEVEL_UNINITIALIZED;

struct l_transitions
{
    levels_t down;
    levels_t up;
};

struct l_properties
{
    levels_t index;
    unsigned long delay_us;
    int pin;
    struct l_transitions transitions;
};

struct l_properties levels[LEVEL_NUM_LEVELS] = {
//   level,                   delay, pin,                 {down transition,       up transition}
    {LEVEL_UNINITIALIZED,         0, -1,                  {LEVEL_RX,              LEVEL_RX}},
    {LEVEL_RX,               100000, -1,                  {LEVEL_RX,              LEVEL_PREAMP}},
    {LEVEL_PREAMP,           100000, pin_preamp,          {LEVEL_RX,              LEVEL_COAX_RELAY_A}},
    {LEVEL_COAX_RELAY_A,     100000, pin_coax_relay_a,    {LEVEL_PREAMP,          LEVEL_COAX_RELAY_B}},
    {LEVEL_COAX_RELAY_B,     100000, pin_coax_relay_b,    {LEVEL_COAX_RELAY_A,    LEVEL_PA_PTT}},
    {LEVEL_PA_PTT,           100000, pin_pa_ptt,          {LEVEL_COAX_RELAY_B,    LEVEL_TX_INHIBIT}},
    {LEVEL_TX_INHIBIT,       100000, pin_tx_inhibit,      {LEVEL_PA_PTT,          LEVEL_TX}},
    {LEVEL_TX,               100000, -1,                  {LEVEL_TX_INHIBIT,      LEVEL_TX}}
};

unsigned long countdown_us = 0;

unsigned long micros_previous_loop = 0;

void setState(states_t new_state)
{

    if(state == new_state)
    {
        return;
    }

    //Serial.print("state = ");
    //Serial.print(state);
    //Serial.print(", new_state = ");
    //Serial.println(new_state);

    switch(new_state)
    {
        default:
        case STATE_RX:
        {
            if(state == STATE_UNINITIALIZED || state == STATE_TRANSITION)
            {
                digitalWrite(pin_rx, 1);
                digitalWrite(pin_tx, 0);
                state = new_state;
                //Serial.println("Entered full RX");
            }
            break;
        }

        case STATE_TX:
        {
            if(state == STATE_TRANSITION)
            {
                digitalWrite(pin_rx, 0);
                digitalWrite(pin_tx, 1);
                state = new_state;
                //Serial.println("Entered full TX");
            }
            break;
        }

        case STATE_TRANSITION:
        {
            if(state == STATE_RX || state == STATE_TX)
            {
                // both 1 for red/green LED to show orange during transition
                digitalWrite(pin_rx, 1);
                digitalWrite(pin_tx, 1);
                state = new_state;
                //Serial.println("Entered transitioning state");
            }
            break;
        }
    }

    //if(state != new_state)
    //{
    //    Serial.print("Illegal state change? ");
    //    Serial.print(state);
    //    Serial.print(" -> ");
    //    Serial.println(new_state);
    //}

}

void setCountdown(unsigned long us)
{
    //if(us > 0)
    //{
    //    Serial.print("Setting countdown: ");
    //    Serial.println(us);
    //}
    countdown_us = us;
}

void transition(bool to_tx)
{
    // We move "up" in levels towards TX and "down" towards RX
    char level_modifier = to_tx ? 1 : -1;
    levels_t new_level = LEVEL_UNINITIALIZED;

    if(to_tx)
    {
        if(level == LEVEL_TX)
        {
            // We're already at the top
            return;
        }
        new_level = levels[level].transitions.up;
    }
    else
    {
        if(level == LEVEL_RX)
        {
            // We're already at the bottom
            return;
        }
        new_level = levels[level].transitions.down;
    }

    //Serial.print("Transition: TX = ");
    //Serial.print(to_tx);
    //Serial.print(", level = ");
    //Serial.print(level);
    //Serial.print(", new_level = ");
    //Serial.println(new_level);

    switch(new_level)
    {
        default:
        case LEVEL_RX:
        {
            if(level != LEVEL_UNINITIALIZED)
            {
                // Unset pin for previous level
                digitalWrite(levels[level].pin, 0);
            }
            
            // Set minimum delay to stay in RX before accepting new state.
            setCountdown(levels[level].delay_us);
            
            // Set level and state
            level = new_level;
            setState(STATE_RX);
            
            break;
        }
        case LEVEL_PREAMP:
        {
            if(to_tx)
            {
                setState(STATE_TRANSITION);
                digitalWrite(levels[new_level].pin, 1);
            }
            else
            {
                digitalWrite(levels[level].pin, 0);
            }
            setCountdown(levels[new_level].delay_us);
            level = new_level;
            break;
        }
        case LEVEL_COAX_RELAY_A:
        {
            if(to_tx)
            {
                digitalWrite(levels[new_level].pin, 1);
            }
            else
            {
                digitalWrite(levels[level].pin, 0);
            }
            setCountdown(levels[new_level].delay_us);
            level = new_level;
            break;
        }
        case LEVEL_COAX_RELAY_B:
        {
            if(to_tx)
            {
                digitalWrite(levels[new_level].pin, 1);
            }
            else
            {
                digitalWrite(levels[level].pin, 0);
            }
            setCountdown(levels[new_level].delay_us);
            level = new_level;
            break;
        }
        case LEVEL_PA_PTT:
        {
            if(to_tx)
            {
                digitalWrite(levels[new_level].pin, 1);
            }
            else
            {
                digitalWrite(levels[level].pin, 0);
            }
            setCountdown(levels[new_level].delay_us);
            level = new_level;
            break;
        }
        case LEVEL_TX_INHIBIT:
        {
            if(to_tx)
            {
                digitalWrite(levels[new_level].pin, 1);
            }
            else
            {
                setState(STATE_TRANSITION);
                digitalWrite(levels[level].pin, 0);
            }
            setCountdown(levels[new_level].delay_us);
            level = new_level;
            break;
        }
        case LEVEL_TX:
        {
            // Set minimum delay to stay in TX before accepting new state.
            setCountdown(levels[new_level].delay_us);
            
            // Set level and state
            level = new_level;
            setState(STATE_TX);
            
            break;
        }
    }

    //Serial.print("Transitioned to level ");
    //Serial.println(level);

}

void Initialize()
{

    //Serial.println("Initializing...");

    // Set each pin as output and to a safe-ish state, then set state to RX.
    pinMode(levels[LEVEL_TX_INHIBIT].pin, OUTPUT);
    digitalWrite(levels[LEVEL_TX_INHIBIT].pin, 0);
    //Serial.println("TX Inhibit...");
    delay(levels[LEVEL_TX_INHIBIT].delay_us / 1000);

    pinMode(levels[LEVEL_PA_PTT].pin, OUTPUT);
    digitalWrite(levels[LEVEL_PA_PTT].pin, 0);
    //Serial.println("PA PTT...");
    delay(levels[LEVEL_PA_PTT].delay_us / 1000);

    pinMode(levels[LEVEL_COAX_RELAY_B].pin, OUTPUT);
    digitalWrite(levels[LEVEL_COAX_RELAY_B].pin, 0);
    //Serial.println("Coax relay B...");
    delay(levels[LEVEL_COAX_RELAY_B].delay_us / 1000);

    pinMode(levels[LEVEL_COAX_RELAY_A].pin, OUTPUT);
    digitalWrite(levels[LEVEL_COAX_RELAY_A].pin, 0);
    //Serial.println("Coax relay A...");
    delay(levels[LEVEL_COAX_RELAY_A].delay_us / 1000);

    pinMode(levels[LEVEL_PREAMP].pin, OUTPUT);
    digitalWrite(levels[LEVEL_PREAMP].pin, 0);
    //Serial.println("Pre-amplifier...");
    delay(levels[LEVEL_PREAMP].delay_us / 1000);

    pinMode(pin_tx, OUTPUT);
    digitalWrite(pin_tx, 0);
    
    pinMode(pin_rx, OUTPUT);
    digitalWrite(pin_rx, 0);
    
    pinMode(pin_txenable, INPUT);

    transition(false);
}

unsigned long getDeltaMicros()
{
    unsigned long delta_micros = 0;
    unsigned long this_micros = micros();

    // Check for wrap-around of micros counter
    if(this_micros < micros_previous_loop)
    {
        // Add the remainder until wrap-around for previous loop
        delta_micros = (unsigned long)-1 - micros_previous_loop;

        // Add this loop's micros
        delta_micros += this_micros;
    }
    else
    {
        delta_micros = this_micros - micros_previous_loop;
    }

    micros_previous_loop = this_micros;

    return delta_micros;
}

void setup()
{
    //Serial.begin(115200);
    //delay(500);

    Initialize();
    //delay(500);
}

void loop()
{
    static bool first = true;
    bool txenable = false;
    
    unsigned long delta_micros = getDeltaMicros();
    // Don't count down if already at zero
    if(delta_micros && countdown_us)
    {
        if(countdown_us >= delta_micros)
        {
            countdown_us -= delta_micros;
            //Serial.print(".");
            first = true;
        }
        else
        {
            //Serial.print("Countdown reached near zero: ");
            //Serial.println(countdown_us);
            setCountdown(0);
        }
    }
    
    if(countdown_us < (loop_interval_ms * 1000))
    {
        if(first)
        {
            Serial.println();
            first = false;
        }
        txenable = digitalRead(pin_txenable);
        //Serial.print("Time's up! TXEnable: ");
        //Serial.println(txenable);
        transition(txenable);
    }
    //delay(loop_interval_ms);
}

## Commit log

2023-07-02 Added PTT circuit
2023-07-08 It werks! (#1)
    * Baby steps.
    VS Code Arduino extension apparently doesn't play well with remote sessions, so have to resort to traditional SSH/X.
    * Something like this?
    Overly complicated, but meh.
    * Yay! It works!
    * Stop tracking arduino.json.
    * Add .vscode to gitignore
    [arduino-sequencer.ino]
2023-07-08 Commented out loop interval and debug. (#2)
    Should be a bit snappier in reacting to TX Enable, now.
    Still randomly chosen interval for steps, though.
    [arduino-sequencer.ino]
2023-07-15 Removed unused transition table. (#3)
    RX and TX LED on during transition.
2023-07-15 Added PDFs of schematic and perf board prototype layout. (#4)
2023-07-24 Added KiCad project with prototype breadboard layout.
    [LB6ZH Sequencer - Track-redux.kicad_pcb, LB6ZH Sequencer Low-High Select.kicad_sch, LB6ZH Sequencer Optocoupler Drive.kicad_sch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]
